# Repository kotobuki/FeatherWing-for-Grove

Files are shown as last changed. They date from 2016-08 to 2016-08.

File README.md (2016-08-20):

# FeatherWing for Grove

A bridge between the [**Grove**](http://www.seeedstudio.com/wiki/Category:Grove) family by the Seeed Studio and [**Feather**](https://www.adafruit.com/feather) by the Adafruit Industries.

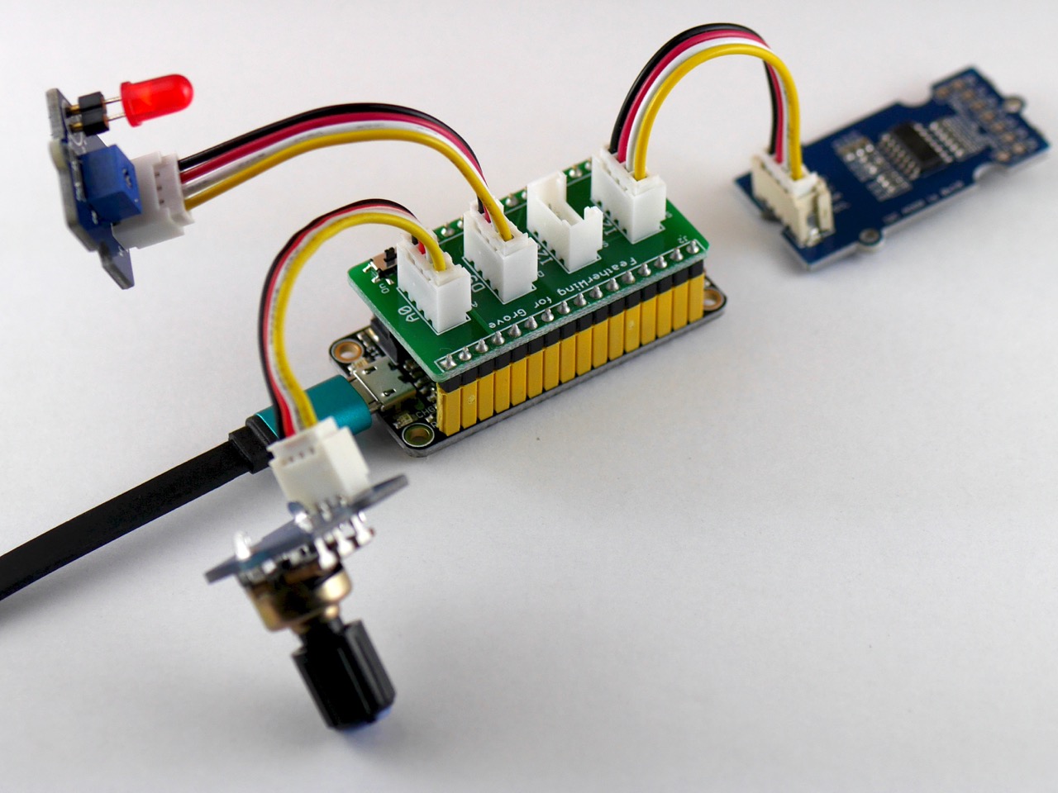
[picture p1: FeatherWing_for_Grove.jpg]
FeatherWing_for_Grove


## Bill of Materials

|Part/Designator|Manufacture Part Number/Seeed SKU|Quantity|
|---|---|---|
|PCB||1|
|J1|Digi-Key: [S1011EC-12-ND](http://www.digikey.com/product-search/en?keywords=S1011EC-12-ND)|1|
|J2|Digi-Key: [S1011EC-16-ND](http://www.digikey.com/product-search/en?keywords=S1011EC-16-ND)|1|
|J3,J4,J5,J6|Seeed SKU: [320110033](http://www.seeedstudio.com/depot/index.php?main_page=opl_info&opl_id=4)|4|
|SW1|Seeed SKU: [311030001](http://www.seeedstudio.com/depot/index.php?main_page=opl_info&opl_id=625)|1|

## How to 'Compile'?

Place an order at the [Fusion PCBA prototype](http://www.seeedstudio.com/service/index.php?r=pcb) service.

## Compatible Grove Modules

* Sensors
  * [Grove - Switch(P)](http://www.seeedstudio.com/wiki/Grove_-_Switch(P))
  * [Grove - Rotary Angle Sensor](http://www.seeedstudio.com/wiki/Grove_-_Rotary_Angle_Sensor)
  * [Grove - Slide Potentiometer](http://www.seeedstudio.com/wiki/Grove_-_Slide_Potentiometer)
  * [Grove - Touch Sensor](http://www.seeedstudio.com/wiki/Grove_-_Touch_Sensor)
  * [Grove - Light Sensor](http://www.seeedstudio.com/wiki/Grove_-_Light_Sensor)
  * [Grove - Single Axis Analog Gyro](http://www.seeedstudio.com/wiki/Grove_-_Single_Axis_Analog_Gyro)
  * [Grove - Button](http://www.seeedstudio.com/wiki/Grove_-_Button)
  * [Grove - Q Touch Sensor](https://seeedstudio.com/Grove-Q-Touch-Sensor-p-1854.html)
* Actuators
  * [Grove - LED Socket Kit](http://www.seeedstudio.com/wiki/Grove_-_LED)
  * [Grove - Buzzer](http://www.seeedstudio.com/wiki/Grove_-_Buzzer)
  * [Grove - Vibration Motor](http://www.seeedstudio.com/wiki/Grove_-_Vibration_Motor)
  * [Grove - Servo](http://www.seeedstudio.com/wiki/Grove_-_Servo)

# License Information

This design document is licensed by Shigeru Kobayashi under the terms of the [Creative Commons Attribution-ShareAlike 4.0 International Public License](http://creativecommons.org/licenses/by-sa/4.0/).

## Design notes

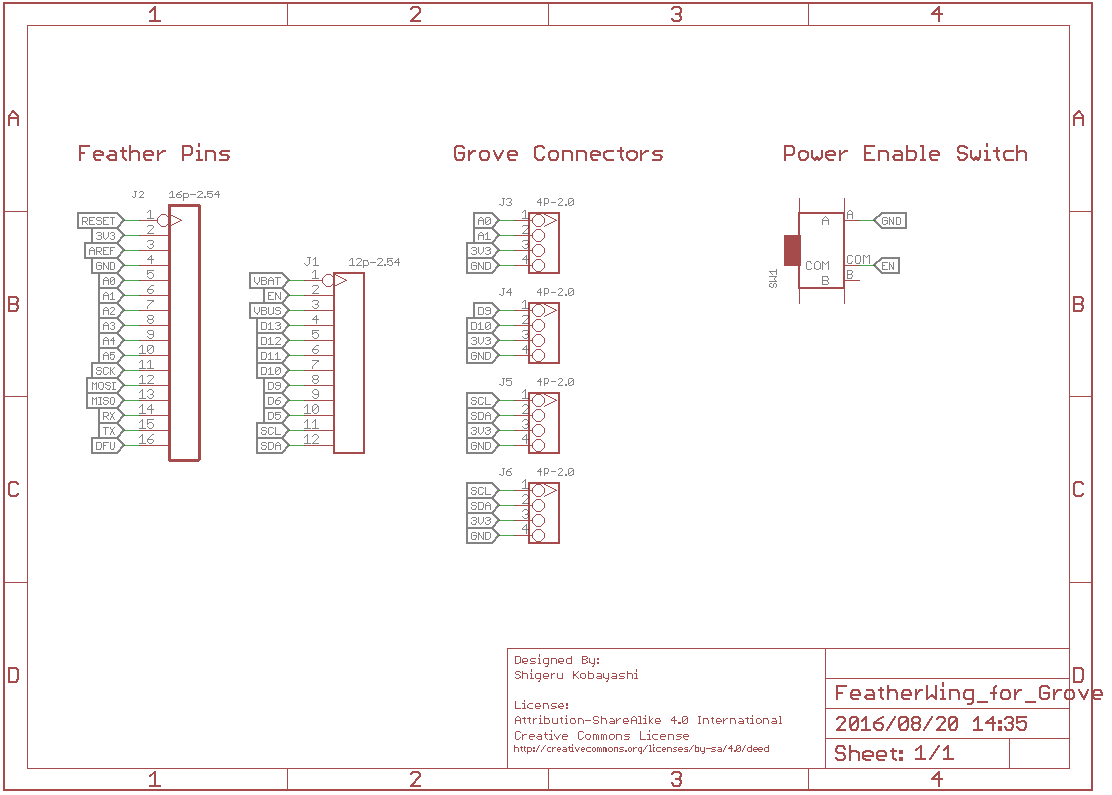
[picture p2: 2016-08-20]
FeatherWing_for_Grove_sch.png

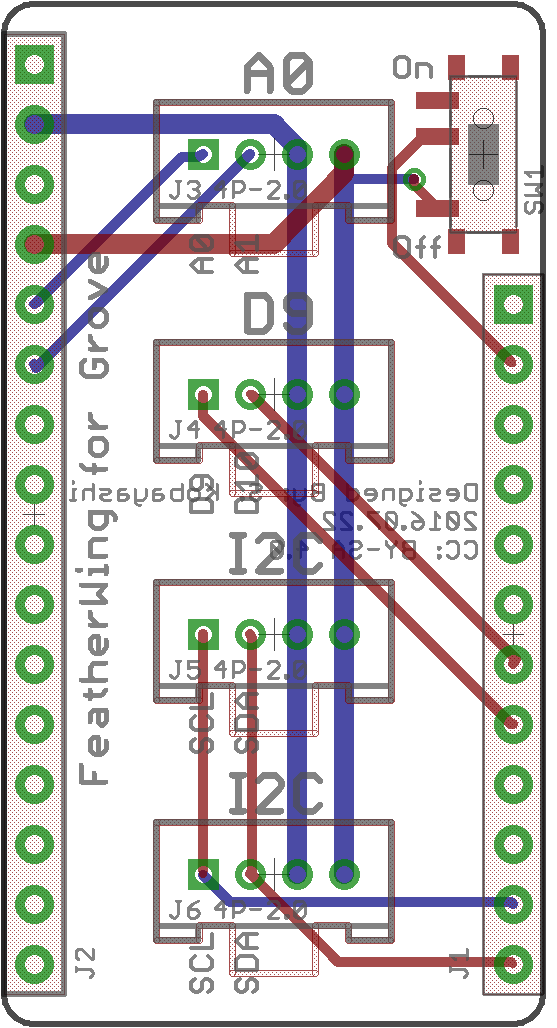
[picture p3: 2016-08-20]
FeatherWing_for_Grove_brd.png

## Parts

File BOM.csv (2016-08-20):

Part/Designator | Manufacture Part Number/Seeed SKU | Quantity
J1 | PRPC012SAAN-RC | 1
J2 | PRPC016SAAN-RC | 1
J3,J4,J5,J6 | 320110033 | 4
SW1 | 311030001 | 1

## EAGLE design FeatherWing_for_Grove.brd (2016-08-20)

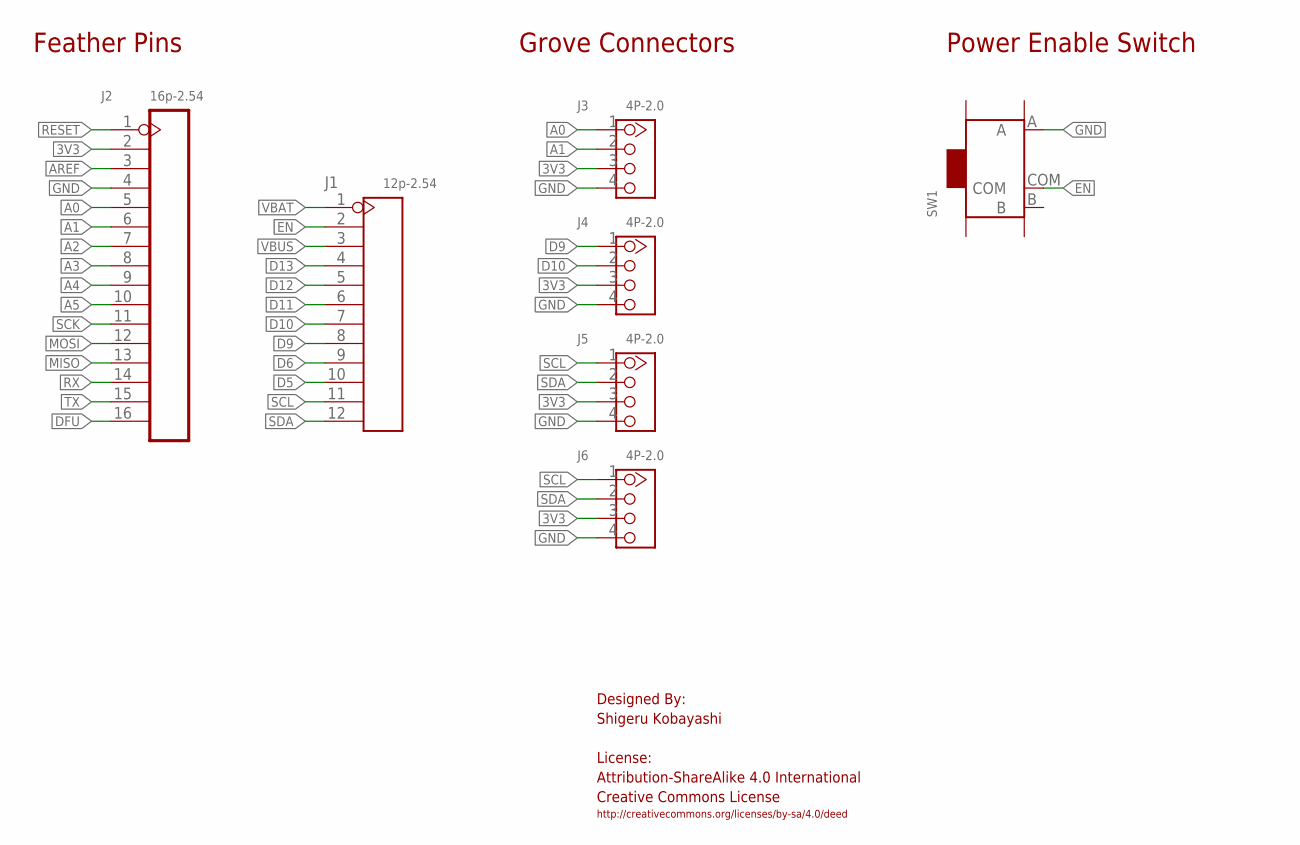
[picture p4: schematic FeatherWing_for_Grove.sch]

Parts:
J1: 12p-2.54; H12-2.54
J2: 16p-2.54; H16-2.54
J3, J4, J5, J6: 4P-2.0; HW4-2.0
SW1: SMD-TOGGLE-SWITCH-ON-ON(3+4P-6.7X2.7MM); SW7-SMD-L6.7X2.7X3.2MM

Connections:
3V3: J2.2, J3.3, J4.3, J5.3, J6.3
A0: J2.5, J3.1
A1: J2.6, J3.2
A2: J2.7
A3: J2.8
A4: J2.9
A5: J2.10
AREF: J2.3
D5: J1.10
D6: J1.9
D9: J1.8, J4.1
D10: J1.7, J4.2
D11: J1.6
D12: J1.5
D13: J1.4
DFU: J2.16
EN: J1.2, SW1.COM
GND: J2.4, J3.4, J4.4, J5.4, J6.4, SW1.A
MISO: J2.13
MOSI: J2.12
RESET: J2.1
RX: J2.14
SCK: J2.11
SCL: J1.11, J5.1, J6.1
SDA: J1.12, J5.2, J6.2
TX: J2.15
VBAT: J1.1
VBUS: J1.3

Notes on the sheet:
Feather Pins
Grove Connectors
Power Enable Switch
Designed By: Shigeru Kobayashi License: Attribution-ShareAlike 4.0 International Creative Commons License
http://creativecommons.org/licenses/by-sa/4.0/deed

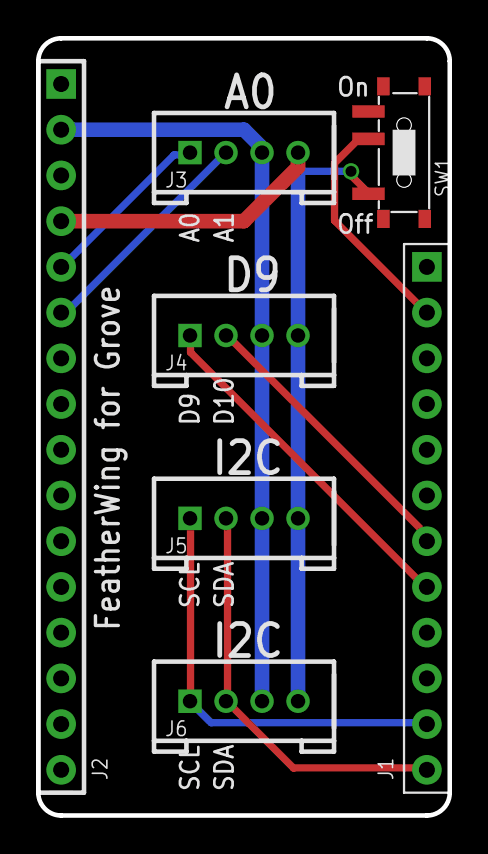
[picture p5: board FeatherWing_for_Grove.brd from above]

Board: 2 copper layers, 22.9 x 43.2 mm, 7 parts (0 on the bottom side), 9 nets.
